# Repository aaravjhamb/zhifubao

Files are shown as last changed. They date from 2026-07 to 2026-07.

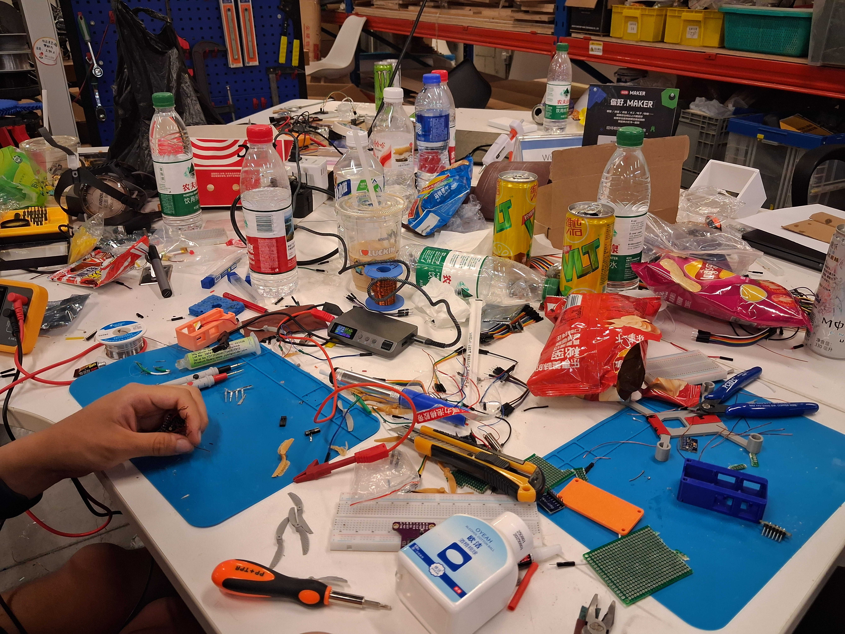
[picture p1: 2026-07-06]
assets/41281.jpg

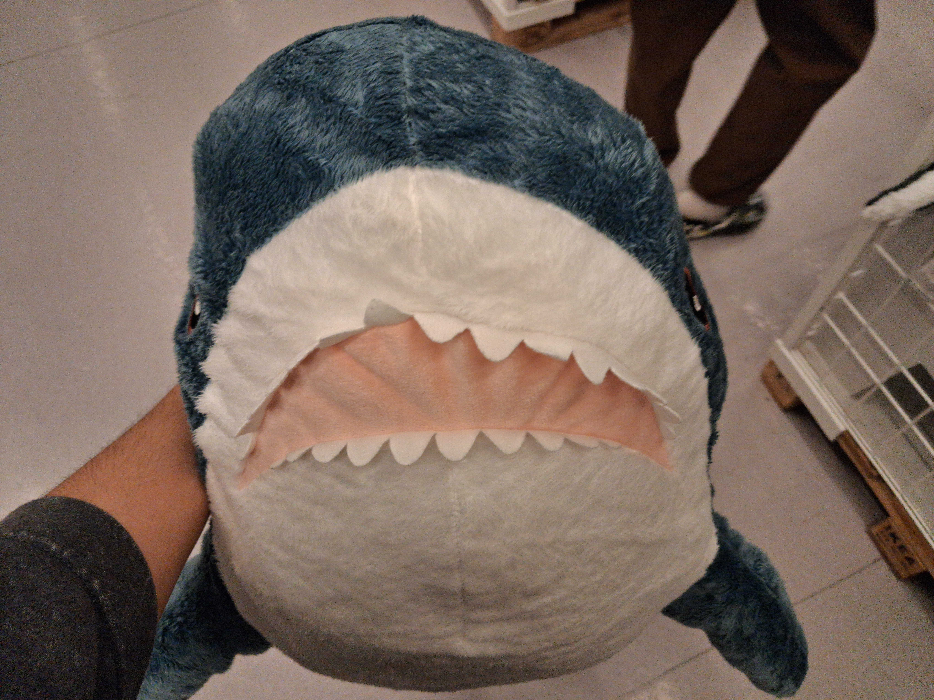
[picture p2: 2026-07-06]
assets/41276.jpg

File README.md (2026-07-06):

# ZHIFUBAO
you might have some questions regarding the name of the drone, lets not go there just that it translates to alipay in chinese

ESP32-based motion controlled drone!!

# WHY
HEYHEYHEY SO WE ARE IN SHENZEN, 72 HOURS, IN THE CORE CITY OF COMPONENTS, SO WE DECIDED TO MAKE A GESTURE CONTROLLED DRONE!!!!

## WHAT IT IS
ZHIFUBAO is a gesture-controlled drone built for Fallout in Shenzhen.  
Instead of using a normal controller, we use hand movement as input to control the drone.

Tilt hand = drone moves. sounds easy enough fr

## Zine
zhifubao

## HOW IT WORKS
- A motion sensor / IMU reads hand movement
- A microcontroller processes that data
- Gestures are mapped to drone controls like pitch, roll, yaw, and throttle
- Commands are sent wirelessly to the drone
- The drone (hopefully) listens

## WIRING DIAGRAM


### actual wiring 


# BTS

<p align="center">
  
  
  
</p>

<p align="center">
  
  
</p>

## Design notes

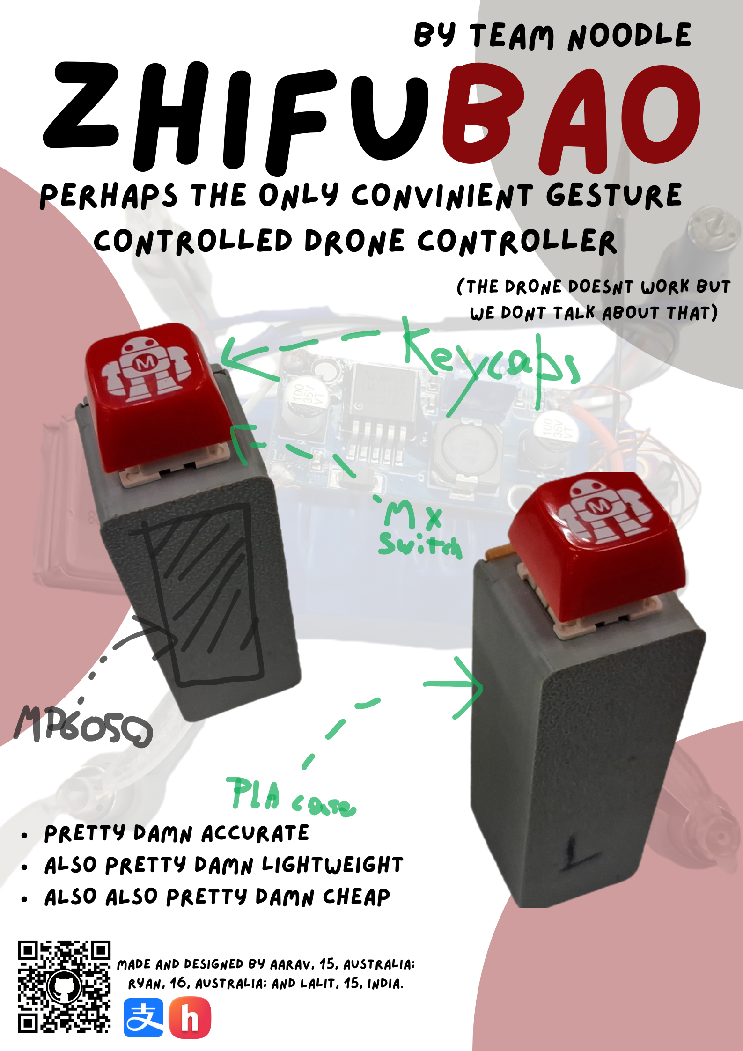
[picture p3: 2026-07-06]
zine/zhifubao.png

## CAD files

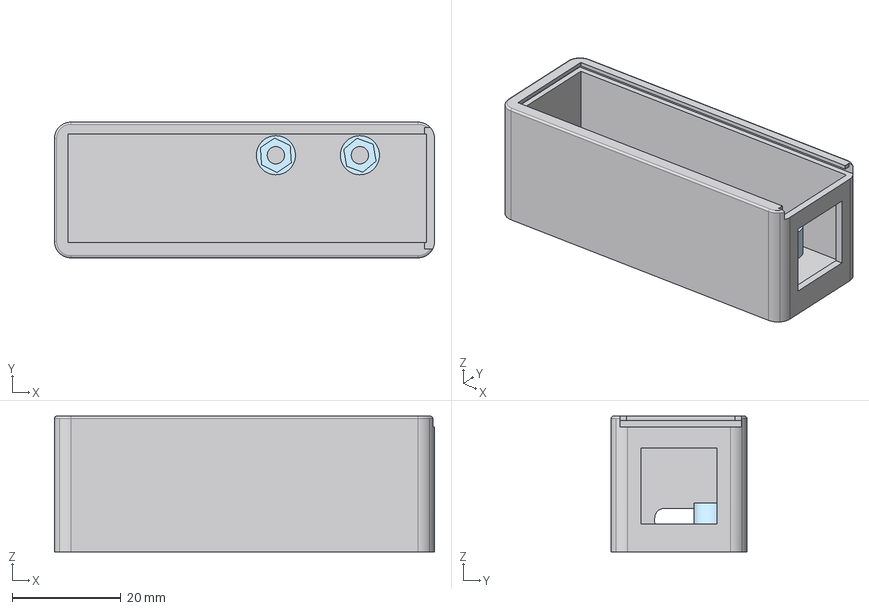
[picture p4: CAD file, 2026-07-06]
CAD/3d print/controller case.step
70.0 x 25.0 x 25.0 mm

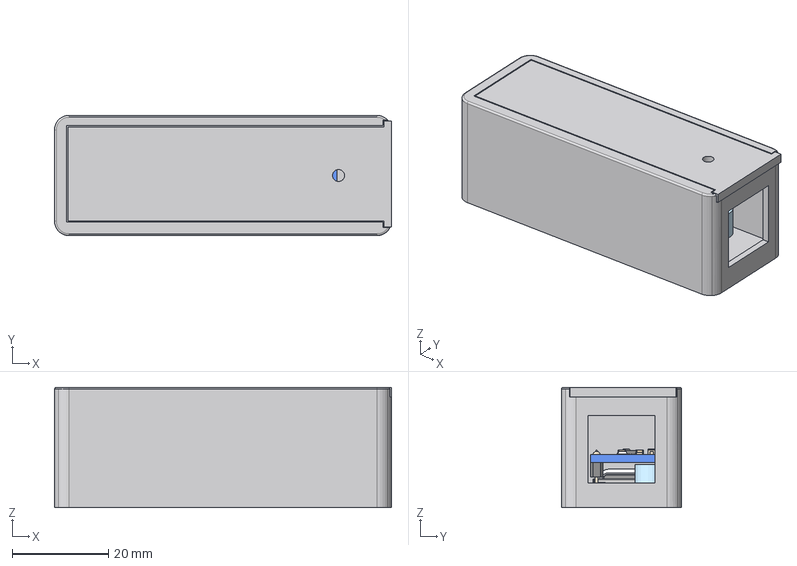
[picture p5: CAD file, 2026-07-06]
CAD/Assembled/controller.step
70.0 x 25.0 x 25.0 mm
BOSS-EXTRUDE14_8_
BOSS-EXTRUDE7_4_
BOSS-EXTRUDE7_3_
BOSS-EXTRUDE14_4_
BOSS-EXTRUDE14_2_
BOSS-EXTRUDE14_11_
BOSS-EXTRUDE7_7_
BOSS-EXTRUDE14_9_
BOSS-EXTRUDE14_3_
BOSS-EXTRUDE14_7_
MIRROR2
BOSS-EXTRUDE14_5_
BOSS-EXTRUDE14_12_
BOSS-EXTRUDE7_8_
BOSS-EXTRUDE7_1_
BOSS-EXTRUDE14_10_
BOSS-EXTRUDE7_9_
BOSS-EXTRUDE14_6_
BOSS-EXTRUDE14_1_
BOSS-EXTRUDE7_6_
BOSS-EXTRUDE7_2_
CUT-EXTRUDE5
BOSS-EXTRUDE7_5_
Shield
Pins x 2
U.FL-R-SMT-1_10_ v1
Board_001
SOT25_001
0603 Capacitor_001
0603 Capacitor_002
0603 Capacitor_003
0603 Capacitor_004
0603 Capacitor_005
0603 Capacitor_006
0603 Resistor_001
0603 Resistor_002
0603 Resistor_003
0603 Resistor_004
SM LED_001
Diode 2_001
24 QFN_001
1x8 Male Header_001
slide_lid

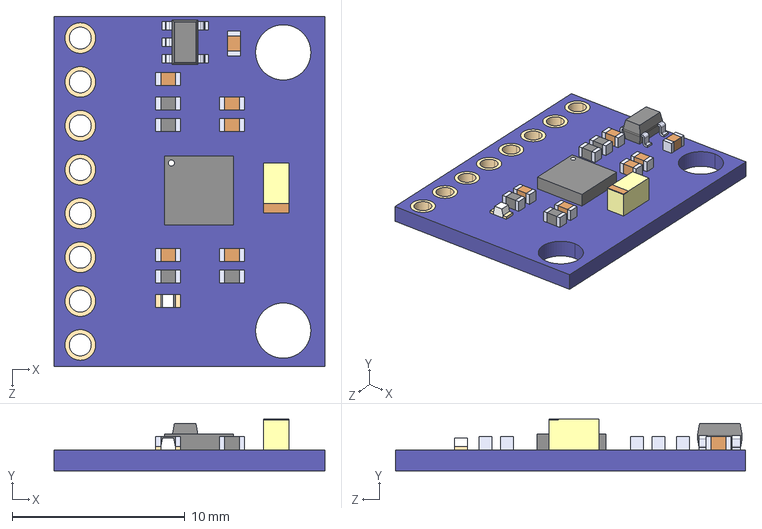
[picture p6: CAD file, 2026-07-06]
hardware/GY-521/GY-521.step
15.7 x 3.00 x 20.3 mm

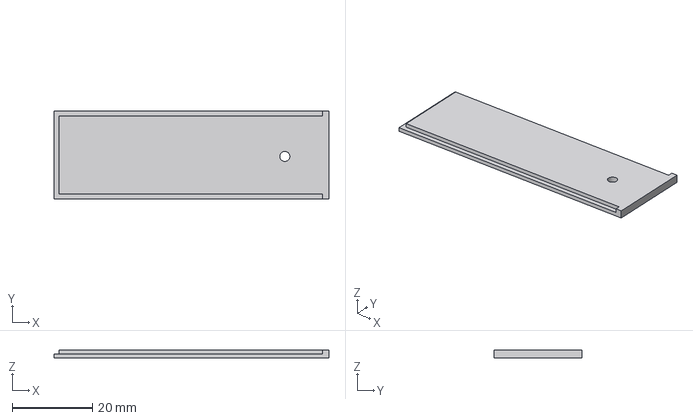
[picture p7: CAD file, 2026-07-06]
CAD/3d print/controller lid.step
68.5 x 22.0 x 2.00 mm

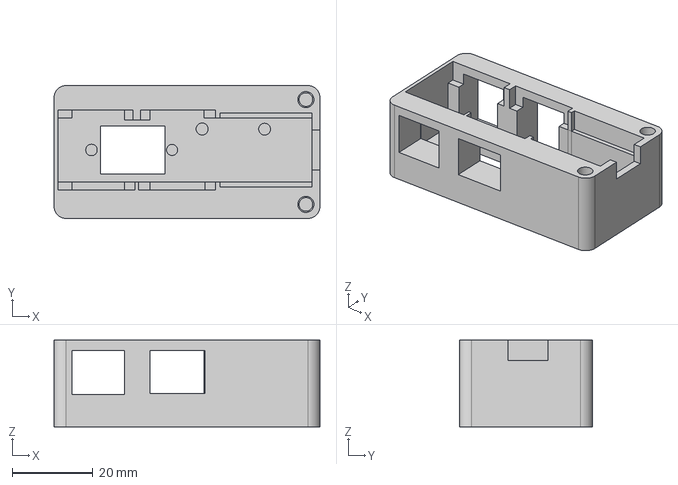
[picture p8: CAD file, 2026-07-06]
CAD/3d print/enclosure.step
66.0 x 33.0 x 21.5 mm

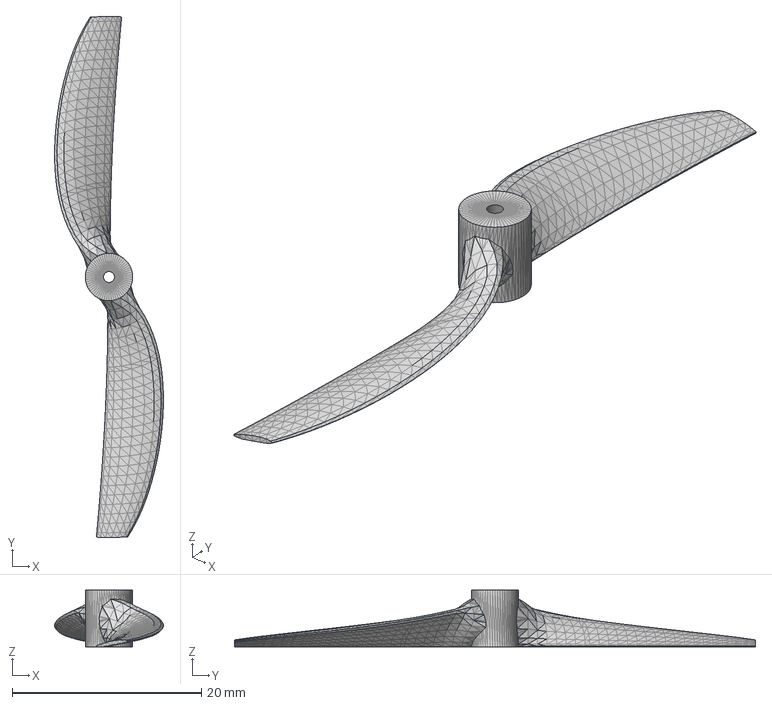
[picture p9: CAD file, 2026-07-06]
CAD/3d print/prop ccw.step
11.5 x 55.0 x 6.00 mm

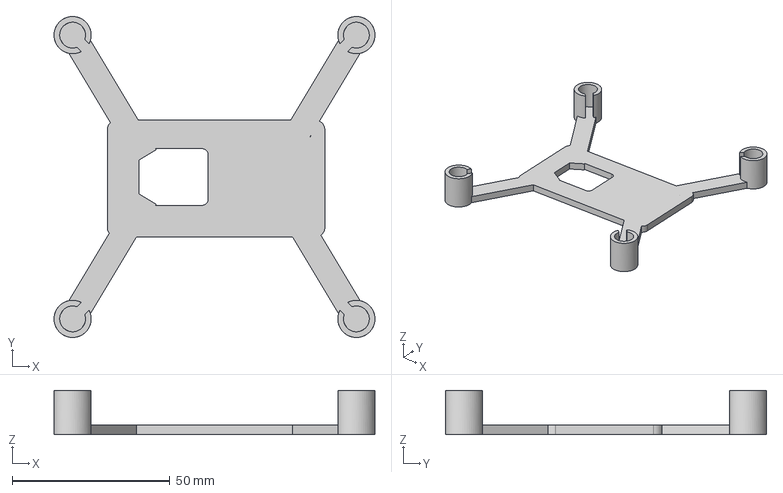
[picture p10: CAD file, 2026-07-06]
CAD/3d print/drone_frame.step
101.8 x 101.8 x 14.0 mm

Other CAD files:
CAD/3d print/prop cw.step
CAD/Source/prop ccw.f3d
CAD/Source/prop cw.f3d

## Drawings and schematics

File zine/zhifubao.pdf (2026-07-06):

z

# perha

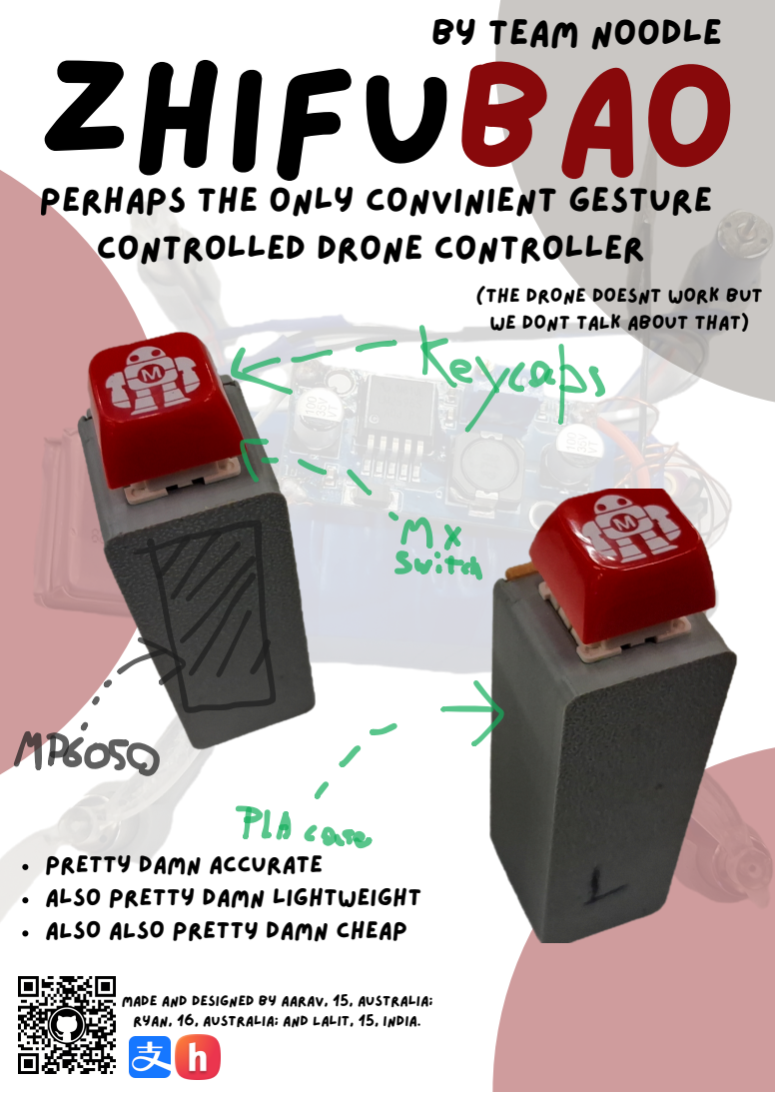
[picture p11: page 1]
nly; convi; nient; gest; ure

by team noodle

controlled drone controller

(THE DRONE DOESNT WORK BUT
WE DONT TALK ABOUT THAT)

pretty damn accurate
also pretty damn lightweight
ALSO ALSO PRETTY DAMN CHEAP

Made and designed by Aarav, 15, Australia;
Ryan, 16, Australia; and Lalit, 15, India.

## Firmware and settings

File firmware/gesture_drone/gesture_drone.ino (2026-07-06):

// gesture_drone.ino — DIY quad flight controller
//   * flies from the two BLE joycons (via the Mac bridge: python3 drone_bridge.py diy)
//   * serves a live web dashboard (attitude horizon, motors, arm/e-stop, PID tuning)
//
// Board: XIAO ESP32-S3 + 2x DRV8833 + MPU6050.
//
// !!!!!!!!!!!!!!!!!!!!!!!!!!!!!!!!!!!!!!!!!!!!!!!!!!!!!!!!!!!!!!!!!!!!!!!!
// !!  PROPS OFF or drone tethered for ALL testing. Keep e-stop ready.  !!
// !!!!!!!!!!!!!!!!!!!!!!!!!!!!!!!!!!!!!!!!!!!!!!!!!!!!!!!!!!!!!!!!!!!!!!!!
//
// Wiring:
//   Motors  M1..M4 -> D0..D3 (GPIO1-4) -> DRV8833 IN1/IN3 ; IN2/IN4 -> GND
//   MPU6050 SDA->D4(GPIO5)  SCL->D5(GPIO6)  VCC->3V3  GND->GND
//   DRV8833 VM -> LiPo+ ; EEP -> 3V3 (always on) ; all grounds common
//
// USE:
//   1. Power the drone. It makes WiFi AP "gesture-drone" (pw flydrone).
//   2. Phone/laptop -> join that AP -> open http://192.168.4.1 for the dashboard.
//   3. Mac (also on that AP) -> python3 drone_bridge.py diy  to fly by gesture.
//   Arm/e-stop work from BOTH the web page and the bridge; e-stop always wins.

#include <Wire.h>
#include <WiFi.h>
#include <WiFiUdp.h>
#include <WebServer.h>
// extra sensors (set to 0 to disable if one misbehaves right before a demo)
#define USE_TOF   1        // VL53L1X  (I2C 0x29) -> altitude.  Needs "VL53L1X" by Pololu
#define USE_FLOW  1        // PMW3901  (SPI)      -> drift.     Needs "Bitcraze PMW3901"
#if USE_TOF
  #include <VL53L1X.h>
#endif
#if USE_FLOW
  #include <SPI.h>
  #include "Bitcraze_PMW3901.h"
#endif

// ---- pins ----
const int PIN_M[4] = {1, 2, 3, 4};   // D0..D3 -> DRV8833 IN1/IN3
const int PIN_SDA  = 5;              // D4
const int PIN_SCL  = 6;              // D5
const int PIN_EEP  = -1;             // -1 = EEP hardwired to 3V3; set 44 for GPIO kill
const uint8_t MPU  = 0x68;
// PMW3901 optical-flow SPI pins (XIAO S3): SCK=7 MISO=8 MOSI=9, CS=43 (D6)
const int PIN_FLOW_CS = 43;

// ---- motor corners: index into PIN_M[] (PIN_M={1,2,3,4} = GPIO1..4) ----
// FL=GPIO3(idx2)  FR=GPIO4(idx3)  RL=GPIO2(idx1)  RR=GPIO1(idx0)
// Props reverse-mounted (diagonals same spin, adjacents opposite) -> no dir code needed.
const int MOT_FL = 2, MOT_FR = 3, MOT_RL = 1, MOT_RR = 0;

// ---- PWM ----
const int PWM_FREQ = 20000, PWM_RES = 10;    // duty 0..1023
#if defined(ESP_ARDUINO_VERSION_MAJOR) && ESP_ARDUINO_VERSION_MAJOR >= 3
void pwmInit(){ for(int i=0;i<4;i++){ ledcAttach(PIN_M[i],PWM_FREQ,PWM_RES); ledcWrite(PIN_M[i],0);} }
void pwmWrite(int i,int d){ ledcWrite(PIN_M[i],d); }
#else
void pwmInit(){ for(int i=0;i<4;i++){ ledcSetup(i,PWM_FREQ,PWM_RES); ledcAttachPin(PIN_M[i],i); ledcWrite(i,0);} }
void pwmWrite(int i,int d){ ledcWrite(i,d); }
#endif

// ---- tuning (live-editable from the web page) ----
float KP = 3.5f, KD = 0.8f, KYAW = 1.2f;
int         THR_MAX  = 900;          // flight throttle ceiling (of 1023). was 700
const int   THR_SPIN = 60;
const float MAX_ANGLE = 22.0f;
const float TILT_CUT  = 60.0f;

// ---- state ----
WiFiUDP  udp;
WebServer web(80);
bool  imuOK=false, armed=false, webEstop=false, testMode=false;
int   testVal[4]={0,0,0,0};          // per-motor test PWM (0..1023) when testMode
float ax,ay,az,gx,gy,gz, gbx=0,gby=0,gbz=0;
float pitch=0, roll=0;
int   mOut[4]={0,0,0,0};
float spRoll=0, spPitch=0, cmdYawRate=0; int cmdThr=0;
unsigned long lastPkt=0;

// extra sensors
#if USE_TOF
VL53L1X tof;
#endif
#if USE_FLOW
Bitcraze_PMW3901 flow(PIN_FLOW_CS);
#endif
bool  tofOK=false, flowOK=false;
int   altMM=0;                 // ToF altitude (mm), -1 = out of range
long  flowX=0, flowY=0;        // accumulated optical-flow drift
int16_t flowDX=0, flowDY=0;    // latest flow delta

void initSensors(){
#if USE_TOF
  tof.setBus(&Wire); tof.setTimeout(200);
  tofOK = tof.init();
  if(tofOK){ tof.setDistanceMode(VL53L1X::Long); tof.setMeasurementTimingBudget(33000); tof.startContinuous(33); }
  Serial.printf("ToF %s\n", tofOK?"OK":"absent");
#endif
#if USE_FLOW
  flowOK = flow.begin();       // uses default VSPI pins + PIN_FLOW_CS
  Serial.printf("Flow %s\n", flowOK?"OK":"absent");
#endif
}
void readSensors(){            // call ~20 Hz, NOT in the fast control loop
#if USE_TOF
  if(tofOK && tof.dataReady()){ int mm=tof.read(false); altMM = tof.timeoutOccurred()?altMM:mm; }
#endif
#if USE_FLOW
  if(flowOK){ int16_t dx,dy; flow.readMotionCount(&dx,&dy); flowDX=dx; flowDY=dy; flowX+=dx; flowY+=dy; }
#endif
}

// ---- IMU ----
void mpuW(uint8_t r,uint8_t v){ Wire.beginTransmission(MPU); Wire.write(r); Wire.write(v); Wire.endTransmission(); }
bool mpuR(uint8_t r,uint8_t*b,uint8_t n){ Wire.beginTransmission(MPU); Wire.write(r);
  if(Wire.endTransmission(false)) return false; if(Wire.requestFrom(MPU,n)!=n) return false;
  for(uint8_t i=0;i<n;i++) b[i]=Wire.read(); return true; }
bool readIMU(){ uint8_t b[14]; if(!mpuR(0x3B,b,14)) return false;
  ax=(int16_t)(b[0]<<8|b[1])/16384.0f; ay=(int16_t)(b[2]<<8|b[3])/16384.0f; az=(int16_t)(b[4]<<8|b[5])/16384.0f;
  gx=(int16_t)(b[8]<<8|b[9])/131.0f-gbx; gy=(int16_t)(b[10]<<8|b[11])/131.0f-gby; gz=(int16_t)(b[12]<<8|b[13])/131.0f-gbz;
  return true; }
void calibrateIMU(){ Serial.println("IMU cal - keep still 2s");
  double sx=0,sy=0,sz=0,sax=0,say=0,saz=0; int n=0; gbx=gby=gbz=0;
  for(int i=0;i<400;i++){ if(readIMU()){sx+=gx;sy+=gy;sz+=gz;sax+=ax;say+=ay;saz+=az;n++;} delay(4);}
  if(n>100){ gbx=sx/n;gby=sy/n;gbz=sz/n; float mx=sax/n,my=say/n,mz=saz/n;
    pitch=atan2f(-mx,sqrtf(my*my+mz*mz))*57.2958f; roll=atan2f(my,mz)*57.2958f; } }
void attitude(float dt){ if(!readIMU()) return;
  pitch+=gy*dt; roll+=gx*dt;
  float m=sqrtf(ax*ax+ay*ay+az*az);
  if(m>0.8f&&m<1.2f){ float ap=atan2f(-ax,sqrtf(ay*ay+az*az))*57.2958f, ar=atan2f(ay,az)*57.2958f;
    pitch=0.98f*pitch+0.02f*ap; roll=0.98f*roll+0.02f*ar; } }

// ---- motors / arming ----
void eep(bool on){ if(PIN_EEP>=0) digitalWrite(PIN_EEP, on?HIGH:LOW); }
void motorsOff(){ for(int i=0;i<4;i++){ mOut[i]=0; pwmWrite(i,0);} }
void disarm(const char*w){ motorsOff(); eep(false); if(armed)Serial.printf("DISARM: %s\n",w); armed=false; }
void arm(){ if(webEstop){ Serial.println("arm refused: estop latched"); return; }
  if(cmdThr>THR_SPIN){ Serial.println("arm refused: throttle up"); return; }
  eep(true); armed=true; Serial.println("ARMED"); }

// ---- UDP command from the bridge ----
void parsePacket(){
  uint8_t b[16]; int n=udp.parsePacket(); if(n<8) return; udp.read(b,sizeof(b));
  if(b[0]!=0xAA||b[7]!=0x55) return;
  if((b[1]^b[2]^b[3]^b[4]^b[5])!=b[6]) return;
  spRoll  = (b[1]-128)/128.0f*MAX_ANGLE;
  spPitch = (b[2]-128)/128.0f*MAX_ANGLE;
  cmdThr  = b[3]<=128 ? 0 : map(b[3],128,255,0,THR_MAX);
  cmdYawRate = (b[4]-128)/128.0f*120.0f;
  bool wantArm=b[5]&1, estop=b[5]&2;
  lastPkt=millis();
  if(estop){ webEstop=true; disarm("bridge estop"); return; }
  if(wantArm && !armed) arm();
  if(!wantArm && armed) disarm("bridge disarm");
}

// ---- control loop ----
void control(float dt){
  if(!imuOK){ if(armed) disarm("no IMU"); return; }   // flight needs the IMU
  attitude(dt);
  if(armed && (fabsf(pitch)>TILT_CUT||fabsf(roll)>TILT_CUT)){ disarm("tilt"); return; }
  if(armed && millis()-lastPkt>500){ disarm("link lost"); return; }
  if(!armed || webEstop){ return; }
  if(cmdThr<THR_SPIN){ motorsOff(); return; }
  float eP=spPitch-pitch, eR=spRoll-roll;
  float pOut=KP*eP - KD*gy;
  float rOut=KP*eR - KD*gx;
  float yOut=KYAW*(cmdYawRate-gz);
  int m[4];
  m[MOT_FL]=cmdThr+pOut+rOut+yOut;
  m[MOT_FR]=cmdThr+pOut-rOut-yOut;
  m[MOT_RL]=cmdThr-pOut+rOut-yOut;
  m[MOT_RR]=cmdThr-pOut-rOut+yOut;
  for(int i=0;i<4;i++){ mOut[i]=constrain(m[i],THR_SPIN,1023); pwmWrite(i,mOut[i]); }
}

// ---- web dashboard ----
const char PAGE[] PROGMEM = R"HTML(
<!DOCTYPE html><html><head><meta name=viewport content="width=device-width,initial-scale=1">
<title>gesture drone</title><style>
body{font-family:system-ui,monospace;background:#0e0e10;color:#eee;margin:0;padding:14px;text-align:center}
h1{font-size:17px;margin:0 0 8px}
#stat{font-weight:700;padding:4px 10px;border-radius:6px}
.armed{background:#7a1f1f;color:#fdd}.safe{background:#245c2e;color:#cfc}.estop{background:#b00;color:#fff}
.wrap{display:flex;gap:14px;justify-content:center;flex-wrap:wrap;align-items:flex-start}
canvas{background:#161618;border-radius:10px}
.quad{position:relative;width:170px;height:170px;background:#161618;border-radius:10px;margin:auto}
.m{position:absolute;width:44px;height:44px;border-radius:50%;background:#333;display:flex;align-items:center;justify-content:center;font-size:12px;color:#bb8}
.arm-btns button,.est button{font-family:inherit;border:0;border-radius:8px;padding:14px;font-size:16px;margin:4px;cursor:pointer;width:130px}
#bArm{background:#245c2e;color:#cfc}#bDis{background:#333;color:#eee}
#bEst{background:#b00;color:#fff;font-weight:700;width:270px;font-size:18px}
.gains{margin-top:8px;font-size:13px}.gains label{display:inline-block;width:270px;margin:3px}
.gains input{vertical-align:middle;width:150px}
.mrow{margin:5px;font-size:14px}.mrow b{color:#8af;display:inline-block;width:26px}
.mrow input[type=range]{vertical-align:middle;width:130px}
.mrow input[type=number]{width:60px;background:#222;color:#eee;border:1px solid #444;border-radius:4px;margin:0 4px}
.mrow .mv{display:inline-block;width:44px}
small{color:#888}
</style></head><body>
<h1>gesture drone <span id=stat class=safe>--</span></h1>
<div class=wrap>
  <canvas id=horizon width=200 height=200></canvas>
  <div>
    <div class=quad id=quad>
      <div class=m id=mFL style="top:8px;left:8px">FL</div>
      <div class=m id=mFR style="top:8px;right:8px">FR</div>
      <div class=m id=mRL style="bottom:8px;left:8px">RL</div>
      <div class=m id=mRR style="bottom:8px;right:8px">RR</div>
    </div>
    <div id=vals style="margin-top:6px;font-size:13px"></div>
    <div id=sens style="margin-top:4px;font-size:13px;color:#8fb"></div>
  </div>
</div>
<div class=arm-btns>
  <button id=bArm onclick="cmd('arm=1')">ARM</button>
  <button id=bDis onclick="cmd('arm=0')">DISARM</button>
</div>
<div class=est><button id=bEst onclick="cmd('estop=1')">EMERGENCY STOP</button>
  <div><small>after e-stop, press DISARM then ARM to clear</small></div></div>

<div id=testpanel style="margin-top:10px;border-top:1px solid #333;padding-top:8px">
  <button id=bTest onclick="toggleTest()" style="font-family:inherit;background:#555;color:#fff;border:0;border-radius:8px;padding:12px;font-size:15px;width:200px;cursor:pointer">MOTOR TEST: off</button>
  <button onclick="allOff()" style="font-family:inherit;background:#333;color:#eee;border:0;border-radius:8px;padding:12px;font-size:14px;margin-left:4px;cursor:pointer">ALL OFF</button>
  <div id=sliders style="margin-top:8px;opacity:.4;pointer-events:none">
    <!-- idx: 2=FL(GPIO3) 3=FR(GPIO4) 1=RL(GPIO2) 0=RR(GPIO1) -->
    <div class=mrow><b>FL</b> GPIO3 <input type=range class=mt data-i=2 min=0 max=1023 value=0><input type=number class=mn data-i=2 min=0 max=1023 value=0><span class=mv>0%</span></div>
    <div class=mrow><b>FR</b> GPIO4 <input type=range class=mt data-i=3 min=0 max=1023 value=0><input type=number class=mn data-i=3 min=0 max=1023 value=0><span class=mv>0%</span></div>
    <div class=mrow><b>RL</b> GPIO2 <input type=range class=mt data-i=1 min=0 max=1023 value=0><input type=number class=mn data-i=1 min=0 max=1023 value=0><span class=mv>0%</span></div>
    <div class=mrow><b>RR</b> GPIO1 <input type=range class=mt data-i=0 min=0 max=1023 value=0><input type=number class=mn data-i=0 min=0 max=1023 value=0><span class=mv>0%</span></div>
    <div class=mrow><b>ALL</b> <input type=number id=mall min=0 max=1023 value=0><button onclick="setAll()" style="font-family:inherit;background:#2a2a2e;color:#8af;border:1px solid #444;border-radius:6px;padding:6px 12px">set all</button></div>
  </div>
  <small>raw PWM 0-1023 · test mode disarms flight · props OFF · e-stop kills it</small>
</div>
<div class=gains>
  <label>KP <input type=range id=kp min=0 max=8 step=0.1></label>
  <label>KD <input type=range id=kd min=0 max=3 step=0.05></label>
  <label>KYAW <input type=range id=ky min=0 max=4 step=0.1></label>
  <button onclick="applyGains()" style="font-family:inherit;background:#2a2a2e;color:#8af;border:1px solid #444;border-radius:6px;padding:8px 14px">apply gains</button>
</div>
<script>
const H=document.getElementById('horizon'),hx=H.getContext('2d');
let rP=0,rR=0;
function drawHorizon(){
  const w=200,h=200,cx=100,cy=100;
  hx.clearRect(0,0,w,h); hx.save();
  hx.translate(cx,cy); hx.rotate(-rR*Math.PI/180);
  const off=rP*2;
  hx.fillStyle='#3a6ea5'; hx.fillRect(-200,-200+off,400,200);   // sky
  hx.fillStyle='#6b4a2b'; hx.fillRect(-200,off,400,200);        // ground
  hx.strokeStyle='#fff'; hx.lineWidth=2; hx.beginPath(); hx.moveTo(-200,off); hx.lineTo(200,off); hx.stroke();
  hx.restore();
  hx.strokeStyle='#ff0'; hx.lineWidth=3; hx.beginPath();
  hx.moveTo(70,100); hx.lineTo(90,100); hx.moveTo(110,100); hx.lineTo(130,100);
  hx.moveTo(100,100); hx.lineTo(100,108); hx.stroke();
  requestAnimationFrame(drawHorizon);
}
requestAnimationFrame(drawHorizon);
function motorColor(v){ const t=Math.min(1,v/1023); const g=Math.round(60+t*160);
  return 'rgb('+Math.round(40+t*180)+','+g+',60)'; }
async function tick(){
 try{ const d=await(await fetch('/data')).json();
  rP=d.pitch; rR=d.roll;
  const s=document.getElementById('stat');
  if(d.estop){s.textContent='E-STOP';s.className='estop';}
  else if(d.armed){s.textContent=d.link?'ARMED':'ARMED (no link)';s.className='armed';}
  else{s.textContent=d.link?'SAFE · linked':'SAFE · no bridge';s.className='safe';}
  const ids=['mFL','mFR','mRL','mRR'];
  for(let i=0;i<4;i++){const e=document.getElementById(ids[i]);e.style.background=motorColor(d.m[i]);
    e.textContent=Math.round(d.m[i]/1023*100)+'%';}
  document.getElementById('vals').textContent=
    'roll '+d.roll.toFixed(0)+'°  pitch '+d.pitch.toFixed(0)+'°  thr '+Math.round(d.thr/7)+'%';
  let ss=[];
  if(d.tofOK)  ss.push('alt '+(d.alt>0?d.alt+' mm':'--'));
  if(d.flowOK) ss.push('flow '+d.fdx+','+d.fdy);
  document.getElementById('sens').textContent=ss.join('   ');
 }catch(e){}
}
setInterval(tick,100);
async function cmd(q){ await fetch('/cmd?'+q); }
async function applyGains(){ await fetch('/gains?kp='+kp.value+'&kd='+kd.value+'&ky='+ky.value); }
fetch('/data').then(r=>r.json()).then(d=>{kp.value=d.kp;kd.value=d.kd;ky.value=d.kyaw;});
let testOn=false;
async function toggleTest(){
  testOn=!testOn;
  await fetch('/test?on='+(testOn?1:0));
  document.getElementById('bTest').textContent='MOTOR TEST: '+(testOn?'ON':'off');
  document.getElementById('bTest').style.background=testOn?'#b06000':'#555';
  const s=document.getElementById('sliders');
  s.style.opacity=testOn?'1':'.4'; s.style.pointerEvents=testOn?'auto':'none';
  if(!testOn) allOff();
}
async function allOff(){
  document.querySelectorAll('.mt').forEach(sl=>{sl.value=0;});
  document.querySelectorAll('.mn').forEach(nb=>{nb.value=0;});
  document.querySelectorAll('.mv').forEach(v=>{v.textContent='0%';});
  for(let i=0;i<4;i++) await fetch('/motor?i='+i+'&v=0');
}
function applyMotor(i,v){
  v=Math.max(0,Math.min(1023,v|0));
  document.querySelector('.mt[data-i="'+i+'"]').value=v;
  document.querySelector('.mn[data-i="'+i+'"]').value=v;
  document.querySelector('.mt[data-i="'+i+'"]').parentElement.querySelector('.mv').textContent=Math.round(v/1023*100)+'%';
  fetch('/motor?i='+i+'&v='+v);
}
document.querySelectorAll('.mt').forEach(sl=>{ sl.addEventListener('input',()=>applyMotor(sl.dataset.i,+sl.value)); });
document.querySelectorAll('.mn').forEach(nb=>{ nb.addEventListener('input',()=>applyMotor(nb.dataset.i,+nb.value)); });
function setAll(){ const v=+document.getElementById('mall').value; for(let i=0;i<4;i++) applyMotor(i,v); }
</script></body></html>
)HTML";

void handleData(){
  bool link = (millis()-lastPkt < 500);
  char b[340];
  snprintf(b,sizeof(b),
    "{\"armed\":%d,\"estop\":%d,\"link\":%d,\"roll\":%.1f,\"pitch\":%.1f,\"thr\":%d,"
    "\"m\":[%d,%d,%d,%d],\"kp\":%.2f,\"kd\":%.2f,\"kyaw\":%.2f,"
    "\"tofOK\":%d,\"alt\":%d,\"flowOK\":%d,\"fdx\":%d,\"fdy\":%d,\"test\":%d}",
    armed, webEstop, link, roll, pitch, cmdThr, mOut[0],mOut[1],mOut[2],mOut[3], KP,KD,KYAW,
    tofOK, altMM, flowOK, flowDX, flowDY, testMode);
  web.send(200,"application/json",b);
}
void handleCmd(){
  if(web.hasArg("estop")){ webEstop=true; testMode=false; for(int i=0;i<4;i++)testVal[i]=0; disarm("web estop"); }
  if(web.hasArg("arm")){
    if(web.arg("arm").toInt()){ webEstop=false; arm(); }
    else disarm("web");
  }
  web.send(200,"text/plain","ok");
}
void handleGains(){
  if(web.hasArg("kp")) KP=web.arg("kp").toFloat();
  if(web.hasArg("kd")) KD=web.arg("kd").toFloat();
  if(web.hasArg("ky")) KYAW=web.arg("ky").toFloat();
  web.send(200,"text/plain","ok");
}
// motor bench test: /test?on=1|0   and   /motor?i=<0..3>&v=<0..1023>
void handleTest(){
  if(web.hasArg("on")){
    testMode = web.arg("on").toInt()!=0;
    disarm("test mode");                       // flight always off during test
    for(int i=0;i<4;i++){ testVal[i]=0; pwmWrite(i,0); }
    webEstop=false;
  }
  web.send(200,"text/plain", testMode?"test on":"test off");
}
void handleMotor(){
  if(testMode && web.hasArg("i") && web.hasArg("v")){
    int i=web.arg("i").toInt(); int v=constrain(web.arg("v").toInt(),0,1023);
    if(i>=0&&i<4) testVal[i]=v;
  }
  web.send(200,"text/plain","ok");
}

void setup(){
  if(PIN_EEP>=0){ pinMode(PIN_EEP,OUTPUT); digitalWrite(PIN_EEP,LOW); }
  pwmInit();
  Serial.begin(115200); delay(300);
  Serial.println("\n=== gesture_drone ===");
  Wire.begin(PIN_SDA,PIN_SCL,(uint32_t)400000);
  mpuW(0x6B,0x00); mpuW(0x1A,0x03);
  uint8_t who=0; imuOK=mpuR(0x75,&who,1);
  Serial.printf("IMU %s (0x%02X)\n", imuOK?"OK":"FAIL", who);
  if(imuOK) calibrateIMU();
  initSensors();
  WiFi.softAP("gesture-drone-test","flydrone");
  Serial.print("AP up: gesture-drone  dashboard http://"); Serial.println(WiFi.softAPIP());
  udp.begin(9000);
  web.on("/", [](){ web.send_P(200,"text/html",PAGE); });
  web.on("/data", handleData);
  web.on("/cmd", handleCmd);
  web.on("/gains", handleGains);
  web.on("/test", handleTest);
  web.on("/motor", handleMotor);
  web.begin();
  Serial.println("bridge: python3 drone_bridge.py diy");
}

void loop(){
  web.handleClient();
  parsePacket();
  if(testMode){                       // bench test: drive pins directly, no control-loop/IMU dependency
    for(int i=0;i<4;i++){ int v=webEstop?0:testVal[i]; mOut[i]=v; pwmWrite(i,v); }
  } else {
    static unsigned long lu=0; unsigned long now=micros();
    if(now-lu>=4000){ float dt=(now-lu)/1e6f; lu=now; if(dt<0.05f) control(dt); }
  }
  static unsigned long ls=0;
  if(millis()-ls>=50){ ls=millis(); readSensors(); }   // 20 Hz sensor telemetry
  static unsigned long dbg=0;
  if(millis()-dbg>=300){ dbg=millis();
    Serial.printf("%s%s thr%4d sp[%+.0f %+.0f] att[%+.0f %+.0f] m %d %d %d %d\n",
      webEstop?"ESTOP ":"", armed?"ARM":"safe", cmdThr, spRoll, spPitch, roll, pitch,
      mOut[0],mOut[1],mOut[2],mOut[3]); }
}

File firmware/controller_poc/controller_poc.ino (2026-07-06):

/*
 * XIAO ESP32-C3  +  MPU6050  ->  BLE orientation + position streamer
 * -------------------------------------------------------------------
 * Reads the MPU6050 over the XIAO's built-in I2C bus, runs a Madgwick
 * IMU filter for orientation, reads an LDR light sensor, and streams
 * both over BLE to a browser using the Web Bluetooth API.
 *
 * Board:   Seeed Studio XIAO ESP32-C3   (Bluetooth LE only)
 * Sensor:  MPU6050 (GY-521), I2C address 0x68
 *
 * Wiring (XIAO ESP32-C3 default I2C):
 *   MPU6050 VCC -> 3V3
 *   MPU6050 GND -> GND
 *   MPU6050 SDA -> D4  (GPIO6)
 *   MPU6050 SCL -> D5  (GPIO7)
 *
 * Recalibration button:
 *   Wire a momentary button from D9 (GPIO9) to GND. GPIO9 uses the
 *   internal pull-up, so it reads HIGH normally and LOW when pressed.
 *   Pressing it re-measures gyro/accel bias (keep the board still and
 *   level!) and saves the result to flash (NVS). Calibration is loaded
 *   automatically on every boot.
 *
 * LDR (light sensor):
 *   Analog input on D2 (GPIO4 / ADC1). Wire as a voltage divider:
 *     3V3 ---[ LDR ]---+---[ 10k ]--- GND
 *                      |
 *                     D2
 *   Reads brighter -> higher value. Streamed normalized to 0.0 .. 1.0.
 *
 * Power / deep-sleep button:
 *   Wire a momentary button from D1 (GPIO3) to GND (internal pull-up,
 *   active-low). Single button, several behaviors:
 *     - Awake, HOLD 5 s     : enter deep sleep (~uA current draw).
 *     - Awake, DOUBLE-CLICK : recalibrate the IMU after a 3 s delay
 *                             (time to place it on a flat, stable surface).
 *     - Asleep, single CLICK: wakes the chip (it restarts fresh).
 *   D1/GPIO3 is used because on the ESP32-C3 only GPIO0-5 can wake the
 *   chip from deep sleep, and GPIO3 (unlike GPIO2) is not a boot
 *   strapping pin, so a wake press can never disturb boot.
 *
 * Arduino IDE setup:
 *   - Boards Manager: install "esp32" by Espressif.
 *   - Select board:   "XIAO_ESP32C3".
 *   - No extra libraries required.
 *
 * Data sent to the browser (little-endian):
 *   21 bytes = 5 float32 (quaternion[w,x,y,z] + light[0..1]) + 1 byte
 *   single-click counter. The counter is bumped on each D1 single-click; the
 *   drone simulator uses it (LEFT board = arm/disarm, RIGHT board = liftoff/
 *   land). Viewers that read only the first 20 bytes are unaffected.
 */

#include <Wire.h>
#include <BLEDevice.h>
#include <BLEServer.h>
#include <BLEUtils.h>
#include <BLE2902.h>
#include <Preferences.h>
#include <esp_sleep.h>
#include <driver/gpio.h>
#include <math.h>
#include <string.h>   // memcpy for the BLE packet

// ---------- Controller identity (must match the website) ----------
// Both boards run this same firmware. Flash ONE as LEFT and ONE as RIGHT by
// setting CONTROLLER_SIDE below, so each advertises a unique name + UUIDs and
// the web app can target them individually.
#define SIDE_LEFT   0
#define SIDE_RIGHT  1
#define CONTROLLER_SIDE  SIDE_LEFT      // <-- set to SIDE_RIGHT for the other board

#if CONTROLLER_SIDE == SIDE_LEFT
  #define DEVICE_NAME         "XIAO-IMU-L"
  #define SERVICE_UUID        "12345678-1234-5678-1234-56789abcde10"
  #define CHARACTERISTIC_UUID "12345678-1234-5678-1234-56789abcde11"
#else
  #define DEVICE_NAME         "XIAO-IMU-R"
  #define SERVICE_UUID        "12345678-1234-5678-1234-56789abcde20"
  #define CHARACTERISTIC_UUID "12345678-1234-5678-1234-56789abcde21"
#endif

// ---------- Recalibration button ----------
#define RECAL_PIN 9          // D9 / GPIO9, active-low to GND

// ---------- Power / deep-sleep button (D1) ----------
// One switch, three gestures while awake:
//   - single click         : bump the click counter -> sends a click event
//                            (sim: LEFT board = arm/disarm, RIGHT = liftoff/land)
//   - double click         : recalibrate the IMU after RECAL_DELAY_MS
//   - hold POWER_HOLD_MS   : enter deep sleep
// (While asleep, any click wakes the chip via hardware.)
#define POWER_PIN        3      // D1 / GPIO3, active-low, deep-sleep-wake capable
#define POWER_HOLD_MS    5000   // hold this long to enter deep sleep
#define CLICK_MAX_MS     600    // a press shorter than this counts as a "click"
#define DOUBLE_PRESS_MS  700    // max gap between the two clicks of a double-press
#define RECAL_DELAY_MS   3000   // wait after a double-press, then calibrate

// ---------- I2C pins ----------
// Normal:  SDA=6 (D4), SCL=7 (D5).  To test a swapped bus, flip these to 7/6.
#define I2C_SDA 7
#define I2C_SCL 6

// ---------- LDR light sensor ----------
#define LDR_PIN 4            // D2 / GPIO4, ADC1 analog input

// Set to 1 to print live accel/gyro/quaternion to the Serial Monitor.
#define DEBUG_IMU 0

// ---------- MPU6050 registers ----------
// Valid MPU6050 addresses are ONLY 0x68 (AD0 low/floating) or 0x69 (AD0 high).
// This is auto-detected in setup(); the value here is just the starting guess.
static uint8_t       MPU_ADDR      = 0x68;
static bool          mpuOK         = false;   // true once the chip is talking
static const uint8_t REG_WHO_AM_I  = 0x75;
static const uint8_t REG_PWR_MGMT1 = 0x6B;
static const uint8_t REG_GYRO_CFG  = 0x1B;
static const uint8_t REG_ACCEL_CFG = 0x1C;
static const uint8_t REG_ACCEL_OUT = 0x3B;   // start of 14-byte burst

// Full-scale sensitivities for the default ranges (±2g, ±250 deg/s)
static const float ACCEL_LSB_PER_G  = 16384.0f;
static const float GYRO_LSB_PER_DPS = 131.0f;
static const float DEG2RAD          = 0.017453292519943295f;

// ---------- Madgwick filter state ----------
static float q0 = 1.0f, q1 = 0.0f, q2 = 0.0f, q3 = 0.0f;  // orientation quaternion
static const float beta = 0.1f;                            // filter gain

// ---------- Calibration (persisted in NVS) ----------
static float gxBias = 0, gyBias = 0, gzBias = 0;   // gyro bias, deg/s
static float axBias = 0, ayBias = 0, azBias = 0;   // accel bias, g
Preferences prefs;

// ---------- Timing ----------
static uint32_t lastMicros = 0;

// ---------- BLE globals ----------
BLEServer*         pServer   = nullptr;
BLECharacteristic* pChar     = nullptr;
volatile bool      connected = false;
volatile uint8_t   clickSeq  = 0;   // ++ on each confirmed D1 single-click; sent in the packet

class ServerCallbacks : public BLEServerCallbacks {
  void onConnect(BLEServer* s) override    { connected = true; }
  void onDisconnect(BLEServer* s) override {
    connected = false;
    BLEDevice::startAdvertising();          // allow the browser to reconnect
  }
};

// ---------------------------------------------------------------
//  I2C helpers
// ---------------------------------------------------------------
void mpuWrite(uint8_t reg, uint8_t val) {
  Wire.beginTransmission(MPU_ADDR);
  Wire.write(reg);
  Wire.write(val);
  Wire.endTransmission();
}
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

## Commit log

2026-07-06 chore: add files
    [GY-521.step, zhifubros.kicad_pcb, zhifubros.kicad_sch]
2026-07-06 cad files
    [drone_frame.step, enclosure.step, prop ccw.f3d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]
2026-07-06 contorller cad
    [controller case.step, controller lid.step, controller.step]
2026-07-06 fix: schema
    [zhifubros.kicad_sch]
